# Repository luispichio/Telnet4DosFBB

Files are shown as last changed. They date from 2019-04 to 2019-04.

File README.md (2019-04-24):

# Telnet4DosFBB
Cliente / Servidor Telnet (Tunel TCP <-> Serial) para DosFBB

Conversor que simula modem teléfonico conectado a puerto serie permitiendo...

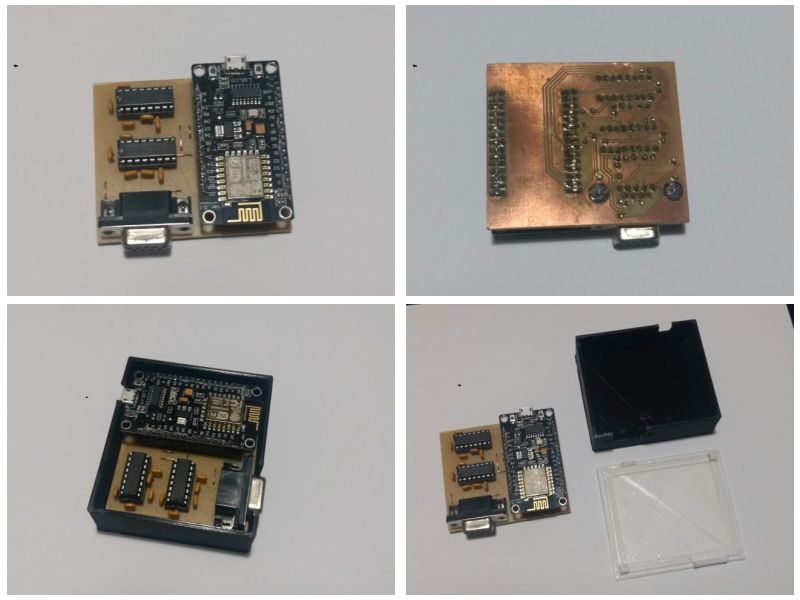
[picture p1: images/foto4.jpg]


# Limitaciones del sistema
1. Una conexión entrante / saliente a la vez: La interfaz de módem telefónico es para conexiones M2M (máquina a máquina).
2. Falso "Telnet": No se reconocen comandos específicos del protocolo, simplemente es un "tunel" TCP <-> Serial.
3. Ancho de banda acotado a interfaz de puerto serial / capacidad de procesamiento de la pc. Con FBBIOS > 1.3 se puede utilizar 56kbps en puerto serie (si la pc lo permite).
4. ...

# Conexionado
El conversor emula (y utiliza) todas las señales de control de un módem estándar.

El cable que debe utilizarse es un DTE <-> DCE con conexión pin a pin (sin inversiones) en los pines: 

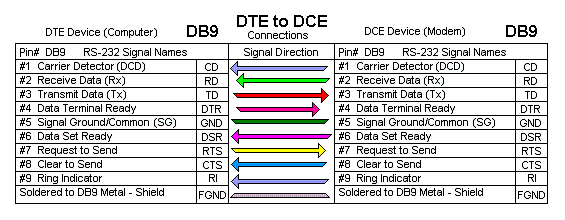
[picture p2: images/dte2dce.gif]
Cable DTE <-> DCE


Para mayor información consultar la documentación oficial: http://www.f6fbb.org/fbbdoc/fmtphnmo.htm

# Configuración

## BBS

Los usuarios del BBS no tiene autorización por defecto para conectar al BBS a traves del módem (Telnet / TCP en nuestro caso).

El SysOp debe habilitar la autorización para acceso por módem para cada usuario vía el comando de SysOP `EU` (editar usuario), habilitando el flag `M` (de módem) y luego asociando una contraseña con el comando `W`.

## Archivos

Se adjuntan archivos [ejemplo de configuración](config/)

### APPEL.BAT
Debe incluír la inicialización del driver fbbios previo a la carga de 'serv.exe'.

Sintaxis: `FBBIOS [# puerto] [dirección de puerto] [# irq]`.

Para mayor información consultar la documentación oficial: http://www.f6fbb.org/fbbdoc/fmtfbbio.htm

```
fbbios 1 03F8 4
serv %1
```

### PORT.SYS

Cantidad de puertos / TNC acorde al sistema
```
#Ports TNCs
1      1
```

Número de puerto serie, interfaz (3 -> Módem telefónico con FBBIOS), dirección de puerto y velocidad en baudios.
Se utiliza 57600 (máximo soportado por FBBIOS >1.3) para mejor rendimiento aunque puede no ser funcional dependiendo de las capacidades del hardware / pc.
La misma configuración aplica al driver FBBIOS que debe precargarse en APPEL.BAT.

```
#Com Interface Address (device)   Baud
1    3         3F8                57600
```

#### Configuración específica
* NbCh -> 1 (la interfaz soporta 1 canal)
* Com -> acorde a la configuración definida previamente
* M/P-Fwd -> inicio / intervalo de fwd de acuerdo al gusto (se aconseja no ser demasiado agresivo)
* Mode -> UMR (U = Normal, M = Módem telefónico, R = Permite conctar en solo lectura aunque no se tengan las credenciales de acceso).
* El resto de los parámetros son ignorados (creo) por la interfaz.

```
# Same number of lines as TNCs:
#
#TNC NbCh Com MultCh Pacln Maxfr NbFwd MxBloc M/P-Fwd Mode Freq
0    0    0   0      0     0     0     0      00/60   ---- File-fwd.
1    1    1   1      250   1     1     5      10/30   UMR  Telnet
```

### INITTNCx.SYS
Lista de comenados que envía el FBB al inicializar y posterior a una conexión.

Reemplazar `x` por número de TNC (depende de configuración en `PORT.SYS`).

Permite configurar parámetros de inicialización del conversor, tales como:
1. SSID y Contraseña de WiFi.
2. DDNS (duckdns.org).
3. Puerto de escucha de servidor telnet.
4. Estado activo / inactivo (fuera de servicio) del servidor telnet.
5. Reinicio del conversor.

Detalle de comandos soportados:

* `C$host:port` -> `host:port`: Servidor / puerto al que conectar.
* `SSID$ssid` -> `ssid`: SSID del WiFi a conectar
* `PASS$password` -> `password`: Contraseña de la red de WiFi
* `PORT$numero` -> `numero`: Puerto de Telnet (conexiones entrantes)
* `DUCK_DNS_UPDATE_TIME$tiempo` -> `tiempo` -> ...
* `DUCK_DNS_DOMAIN$dominio` -> `dominio`: ...
* `DUCK_DNS_TOKEN$token` -> `token`: ...
* `ONLINE$` -> Conversor "en linea": Atiende las conexiones entrantes)
* `OFFLINE$` -> Conversor "fuera de línea": Rechaza (y saluda) las conexiones entrantes.
* `RESET$` -> Reinicio del conversor
  
### MAINTx.SYS

Lista de comenados que envía el FBB al entrar en modo mantenimiento (DOS Gateway, al salir, etc).

Reemplazar `x` por número de TNC (depende de configuración en `PORT.SYS`).

Comando "utilizable":

* `OFFLINE$` -> Conversor "fuera de línea": Rechaza (y saluda) las conexiones entrantes.

### Archivo de forward

La sintaxis del comando de llamada difiere del utilizado en las versiones de FBB que soportal telnet:
Sintaxis: `^MC$$host:puerto^M`

`^M` previo -> para eliminar otro comando / basura que pueda estar encolado en la interfaz.

`C$$host:puerto` -> Conectar a `host` : `puerto` (si no se especifica este último se utiliza 23).

`^M` final -> para que el comando sea aceptado.

```
C C LW6DIO ^MC$$lw6dio.duckdns.org:6300^M
```

### Parámetros configurables desde el Firmware (código fuente)

```
// Modo depuración
// Utilizado para observar el comportamiento del conversor vía puerto serial.
#define DEBUG_MODE
#define DEBUG_BAUD_RATE                             57600

// Generales
// Velocidad en baudios del puerto serial.
#define SERIAL_BAUDRATE                             57600
// Puerto del servidor TCP (conexiones entrantes)
#define DEFAULT_TELNET_PORT                         6300
// Tiempo de reinicio si el conversor no puede conectarse a WiFi (se asume algún problema en hardware / software / externo y que un reinicio "lo pueda solucionar")
#define WIFI_DISCONNECTED_RESET_TIMEOUT_MINUTES     5.0f
// Tiempo de reinicio por inactividad (idem anterior).
#define WITHOUT_ACTIVITY_RESET_TIMEOUT_MINUTES      90.0f
// Tiempo de desconexión automática por inactividad de clientes (tener en cuenta que una vez iniciada la conexión el FBB no controla el estado del cliente TCP y este es el único método para garantizar la liberación)
#define DEFAULT_CLIENT_INACTIVITY_TIMEOUT_SECONDS   60

// Parámetros internos (no se recomienda la modificación)
#define SERIAL_RX_BUFFER_SIZE                       4096
#define SERIAL_RX_BUFFER_CTS_TARGET                 3072

#define TCP_2_SERIAL_BUFFER_SIZE                    8192
#define TCP_RX_FRAME_TIMEOUT                        50
#define SERIAL_2_TCP_BUFFER_SIZE                    1500  //1460?
#define SERIAL_RX_FRAME_TIMEOUT                     50
```

# Referencias
1. Documentación oficial: http://www.f6fbb.org/fbbdoc/doc.htm
2. Espejo en este repositorio: https://luispichio.github.io/Telnet4DosFBB/ (la documentación oficial suele estar fuera de línea)

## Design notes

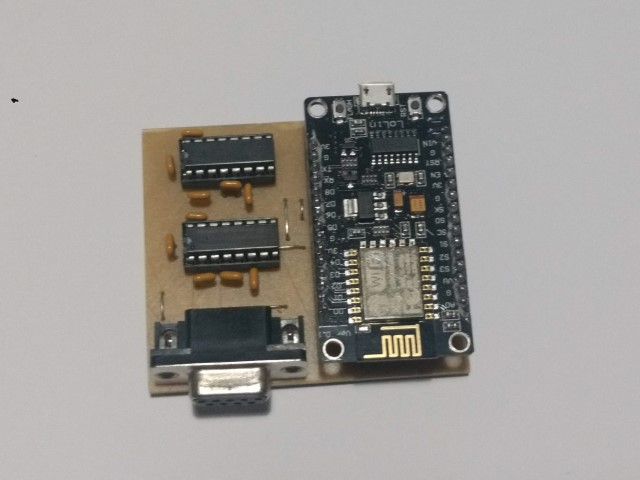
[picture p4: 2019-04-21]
images/foto0.jpg

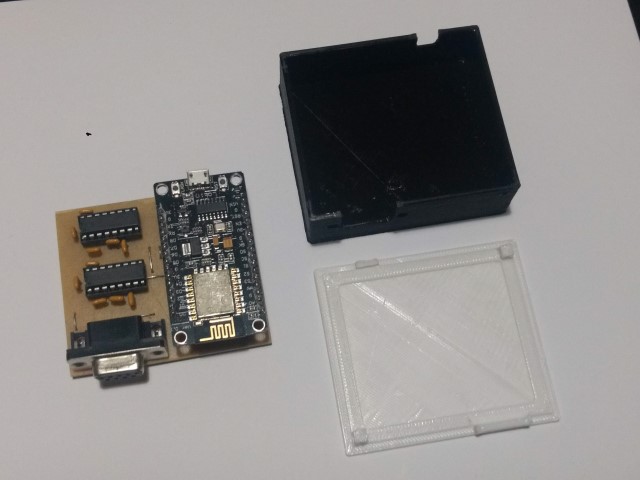
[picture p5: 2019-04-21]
images/foto3.jpg

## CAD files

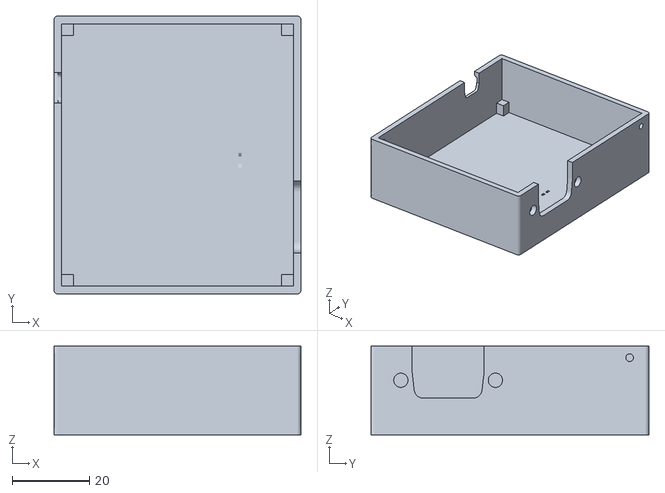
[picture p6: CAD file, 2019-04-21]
box/Caja - Telnet4DosFBB(19112017_0053).stl
64.0 x 72.0 x 23.0

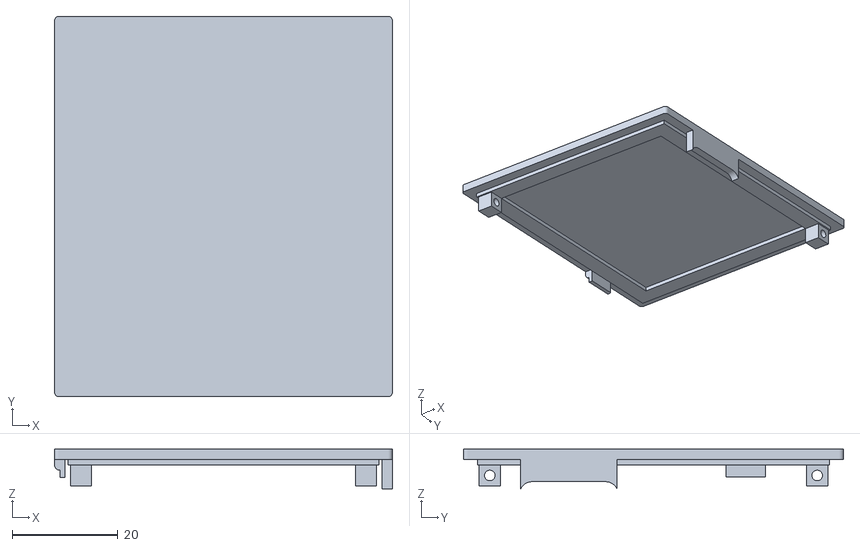
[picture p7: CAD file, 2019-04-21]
box/Tapa - Telnet4DosFBB(19112017_0054).stl
64.0 x 72.0 x 7.55

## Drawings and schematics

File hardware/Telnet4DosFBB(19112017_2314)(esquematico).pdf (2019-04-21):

U2

U3

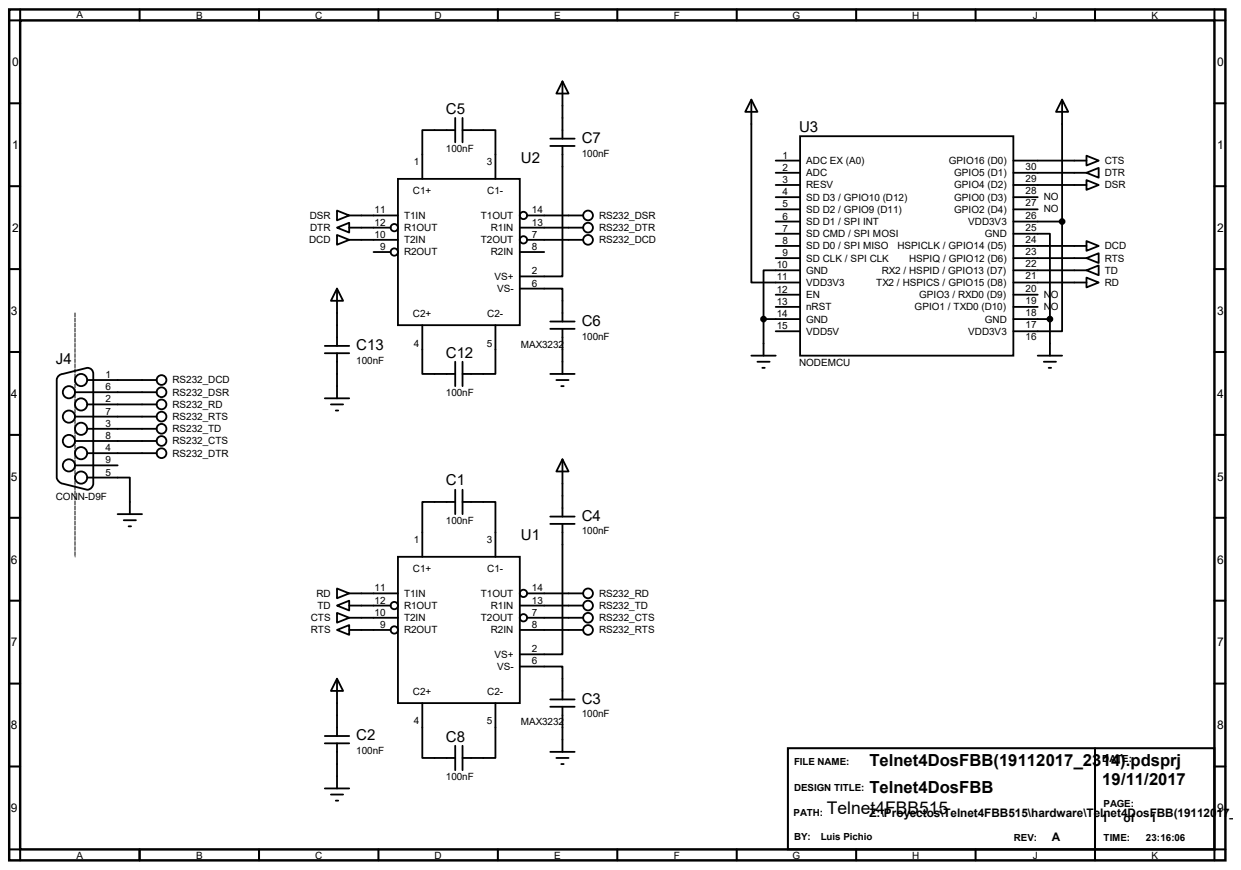
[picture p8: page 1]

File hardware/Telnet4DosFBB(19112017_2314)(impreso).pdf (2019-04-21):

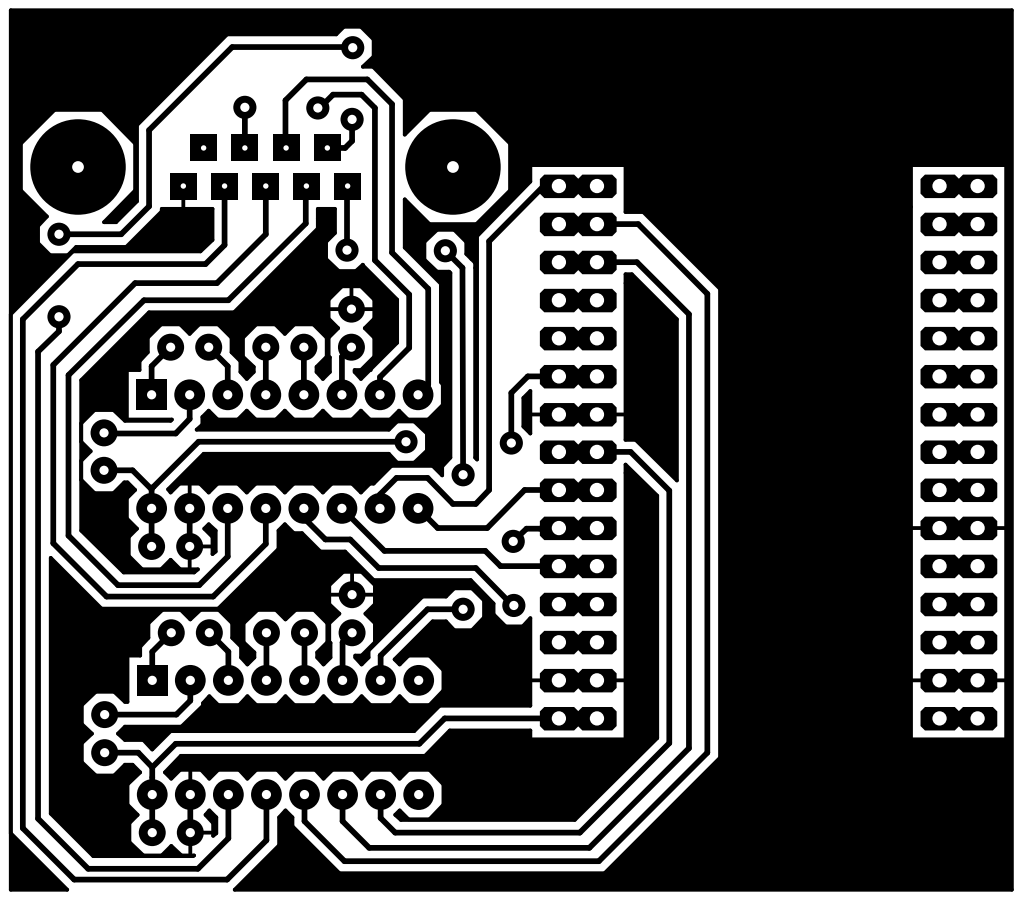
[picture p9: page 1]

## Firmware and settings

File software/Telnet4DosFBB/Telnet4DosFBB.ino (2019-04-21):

/*
MIT License

Copyright (c) 2017 Luis Pichio | https://sites.google.com/site/luispichio/ | https://github.com/luispichio

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
THE SOFTWARE IS PROVIDED "AS IS", WITHOUT WARRANTY OF ANY KIND, EXPRESS OR
IMPLIED, INCLUDING BUT NOT LIMITED TO THE WARRANTIES OF MERCHANTABILITY,
FITNESS FOR A PARTICULAR PURPOSE AND NONINFRINGEMENT. IN NO EVENT SHALL THE
AUTHORS OR COPYRIGHT HOLDERS BE LIABLE FOR ANY CLAIM, DAMAGES OR OTHER
LIABILITY, WHETHER IN AN ACTION OF CONTRACT, TORT OR OTHERWISE, ARISING FROM,
OUT OF OR IN CONNECTION WITH THE SOFTWARE OR THE USE OR OTHER DEALINGS IN THE
SOFTWARE.
*/

#include <ESP8266WiFi.h>
#include <ESP8266HTTPClient.h>
#include "cbuf.h"
#include <EEPROM.h>
#include "CRC8.h"
#include "Utils.h"

//-----------------------------------------------------------------------------
//#define DEBUG_MODE
#define DEBUG_BAUD_RATE                             57600
//-----------------------------------------------------------------------------
#define SERIAL_BAUDRATE                             57600
#define DEFAULT_TELNET_PORT                         6300
#define WIFI_DISCONNECTED_RESET_TIMEOUT_MINUTES     5.0f  //m
#define WITHOUT_ACTIVITY_RESET_TIMEOUT_MINUTES      90.0f  //m
#define DEFAULT_CLIENT_INACTIVITY_TIMEOUT_SECONDS   60  //s
//-----------------------------------------------------------------------------
// ↓↓↓↓↓ parámetros internos ↓↓↓↓↓
//-----------------------------------------------------------------------------
#define SERIAL_RX_BUFFER_SIZE                       4096
#define SERIAL_RX_BUFFER_CTS_TARGET                 3072
//-----------------------------------------------------------------------------
#define TCP_2_SERIAL_BUFFER_SIZE                    8192
#define TCP_RX_FRAME_TIMEOUT                        50
#define SERIAL_2_TCP_BUFFER_SIZE                    1500  //1460?
#define SERIAL_RX_FRAME_TIMEOUT                     50
//-----------------------------------------------------------------------------
//pines
#define CTS_PIN                                     16
#define DCD_PIN                                     14
#define DSR_PIN                                     4
#define RTS_PIN                                     12
#define DTR_PIN                                     5
//-----------------------------------------------------------------------------
//estructura de configuración
//se almacena una única copia en memoria no volátil (flash en este caso)
typedef struct s_config{ 
  char wifiSSID[32];  //ssid de wifi al que se conecta el dispositivo
  char wifiPassword[32];  //contraseña del wifi
  uint16_t serverPort;  //puerto de servidor telnet
  uint16_t clientInactivityTimeout;  //tiempo de desconexión por unactividad (cliente)
  uint16_t duckDNSUpdateTime;  //tiempo de actualización de DNS (duckdns.org)
  char duckDNSDomain[64];  //dominio
  char duckDNSToken[64];  //token
  uint8_t crc; //control de integridad de la estructura
} t_config;
//-----------------------------------------------------------------------------
//variables globales
t_config g_config;  //configuración del sistema (se almacena también una copia en memoria no volátil)
WiFiServer *server;  //server telnet (falso telnet)
WiFiClient client;  //cliente entrante (conexión atentida del servidor) o saliente
long lastClientActivity;  //ultima actividad de cliente (utilizado para reinicio periódico)
bool online = true;  //sistema en línea
long lastWiFiStatusConnected;  //último estado "conectado" de WiFi
long lastDNSUpdate;

#ifdef DEBUG_MODE
  #include <SoftwareSerial.h>
  SoftwareSerial* logger;
  long gTCP2SerialByteCount = 0;
  long gSerial2TCPByteCount = 0;
#endif
//-----------------------------------------------------------------------------
long secondsToMilliseconds(float seconds){
  return seconds * 1000UL;
}
//-----------------------------------------------------------------------------
long minutesToMilliseconds(float minutes){
  return minutes * 60000UL;
}
//-----------------------------------------------------------------------------
long hoursToMilliseconds(float hours){
  return hours * 3600000UL;
}
//-----------------------------------------------------------------------------
//inicialización
void setup() {
  pinMode(DCD_PIN, OUTPUT);
  digitalWrite(DCD_PIN, HIGH);
  pinMode(CTS_PIN, OUTPUT);
  digitalWrite(CTS_PIN, HIGH);
  pinMode(DSR_PIN, OUTPUT);
//  digitalWrite(DSR_PIN, LOW);
  digitalWrite(DSR_PIN, HIGH);
  pinMode(RTS_PIN, INPUT);
  pinMode(DTR_PIN, INPUT);

//puerto serial  
  Serial.begin(SERIAL_BAUDRATE, SERIAL_8N1);
  Serial.setRxBufferSize(SERIAL_RX_BUFFER_SIZE);
  Serial.flush();
  Serial.swap();  //swap a gpio alternativo
  
#ifdef DEBUG_MODE
  logger = new SoftwareSerial(3, 1);
  logger->begin(DEBUG_BAUD_RATE);
  logger->println("\n\nDEBUG_MODE");
#endif

//configuración (almacenada en memoria no volátil)
  EEPROM.begin(512);
  EEPROM.get(0, g_config);
  if (CRC8.calc(0xFF, (uint8_t *)&g_config, offsetof(t_config, crc)) != g_config.crc){  //si la copia tiene integridad incorrecta -> configuración por defecto
#ifdef DEBUG_MODE  
      logger->println("Factory defaults!");
#endif    
      strcpy(g_config.wifiSSID, "");
      strcpy(g_config.wifiPassword, "");
      g_config.serverPort = DEFAULT_TELNET_PORT;
      g_config.clientInactivityTimeout = DEFAULT_CLIENT_INACTIVITY_TIMEOUT_SECONDS;
      g_config.duckDNSUpdateTime = 0;  //DNS desactivado por defecto
      strcpy(g_config.duckDNSDomain, "");
      strcpy(g_config.duckDNSToken, "");
      g_config.crc = CRC8.calc(0xFF, (uint8_t *)&g_config, offsetof(t_config, crc));
      EEPROM.put(0, g_config);
      EEPROM.commit();
  }
   
//wifi
  if (strlen(g_config.wifiSSID))
    WiFi.begin(g_config.wifiSSID, g_config.wifiPassword);  //intentamos conectar
  else
    WiFi.begin();
#ifdef DEBUG_MODE  
  logger->print("Conectando a "); logger->println(g_config.wifiSSID);
#endif  
  while ((WiFi.status() != WL_CONNECTED) && (millis() < secondsToMilliseconds(10.0f)))  //por 10s
    delay(1000);
#ifdef DEBUG_MODE    
  if (WiFi.status() == WL_CONNECTED){
    logger->print("Listo! Para conectar utilice 'telnet ");
    logger->print(WiFi.localIP());
    logger->print(":");
    logger->print(g_config.serverPort);
    logger->println("'");
  } else {
    logger->print("No se pudo conectar a ");
    logger->println(g_config.wifiSSID);
  }
#endif

//servidor telnet (falso telnet en rigor)
  server = new WiFiServer(g_config.serverPort);
  server->begin();
  server->setNoDelay(false);

  lastClientActivity = lastWiFiStatusConnected = lastDNSUpdate = millis();
}
//-----------------------------------------------------------------------------
bool clientConnected(){
  return client && client.connected();
}
//-----------------------------------------------------------------------------
//procesa trama de comandos
void processFBBLine(char *frame){
  char *cmd;
  char *host;
  char *_port;
  int port;
  bool _connected;
  byte retrys = 3;
#ifdef DEBUG_MODE  
  logger->println(frame);
#endif

//comando conectar
  if (cmd = strstr(frame, "C$")){
    cmd += 2;
    host = strtok(cmd, ":");
    _port = strtok(NULL, ":");
    port = atoi(_port);
    if (port == 0)
      port = 23;
    if (host){
      while (!(_connected = client.connect(host, port)) && retrys){
        retrys--;
        delay(100);
      }
      if (_connected){
//        Serial.print("Conectando a "); Serial.print(host); Serial.print(":"); Serial.println(port);
        client.setNoDelay(false);
        digitalWrite(DCD_PIN, LOW);
        lastClientActivity = millis();
      } else {
//        Serial.print("Imposible conectar a "); Serial.print(host); Serial.print(":"); Serial.println(port);
        digitalWrite(DCD_PIN, LOW);
        delay(100);
        digitalWrite(DCD_PIN, HIGH);
      }
    }
  }

//comando SSID de wifi
  if (cmd = strstr(frame, "SSID$")){
    cmd += strlen("SSID$");
    if (strlen(cmd) < 31)
      strcpy(g_config.wifiSSID, cmd);
  }

//comando password de wifi
  if (cmd = strstr(frame, "PASS$")){
    cmd += strlen("PASS$");
    if (strlen(cmd) < 31)
      strcpy(g_config.wifiPassword, cmd);
  }
  
//puerto de servidor telnet
  if (cmd = strstr(frame, "PORT$")){
    cmd += strlen("PORT$");
    g_config.serverPort = atoi(cmd);
  }

//DDNS
  if (cmd = strstr(frame, "DUCK_DNS_UPDATE_TIME$")){
    cmd += strlen("DUCK_DNS_UPDATE_TIME$");
    g_config.duckDNSUpdateTime = atoi(cmd);
  }
  if (cmd = strstr(frame, "DUCK_DNS_DOMAIN$")){
    cmd += strlen("DUCK_DNS_DOMAIN$");
    if (strlen(cmd) < 63)
      strcpy(g_config.duckDNSDomain, cmd);
  }
  if (cmd = strstr(frame, "DUCK_DNS_TOKEN$")){
    cmd += strlen("DUCK_DNS_TOKEN$");
    if (strlen(cmd) < 63)
      strcpy(g_config.duckDNSToken, cmd);
  }
  
//almacenamos configuración en caso de que haya cambios
  uint8_t crc = CRC8.calc(0xFF, (uint8_t *)&g_config, offsetof(t_config, crc));
  if (crc != g_config.crc){
    g_config.crc = crc;
    EEPROM.put(0, g_config);
    EEPROM.commit();
  }

//bbs en línea
  if (strstr(frame, "ONLINE$"))
    online = true;

//bbs fuera de línea
  if (strstr(frame, "OFFLINE$"))
    online = false;

//reinicio (para aplicar la configuración)  
  if (strstr(frame, "RESET$")){
    Serial.swap();
    ESP.restart();
  }
}
//-----------------------------------------------------------------------------
//procesa trama de puerto serial
void processSerialFrame(uint8_t *frame, int size){
  static char bufferRX[256];
  static int bufferSize = 0;  
  while (size--){
    uint8_t b = *frame; frame++;
    if ((b == 0x0a) || (b == 0x0d)){
      if (bufferSize){
        bufferRX[bufferSize] = 0;
        processFBBLine(bufferRX);
        bufferSize = 0;
      }
    } else
      if (bufferSize < 255)  //si mayor a tamaño de buffer -> se pierde contenido
        bufferRX[bufferSize++] = b;
  }
}
//-----------------------------------------------------------------------------
//manejador de conexiones entrantes (servidor telnet)
//atiende nuevos clientes
//envía mensaje y rechaza en caso de no poder atender la conexión
bool check4Clients(void){
  if (server->hasClient()){  //hay nuevo cliente?
    if (online){  //está el servicio en línea?
      if (clientConnected()){  //tenemos cliente -> no podemos atender al nuevo
        WiFiClient _client = server->available();
        _client.println("Todos los canales están ocupados.");  //mensaje de "canales ocupados"
        _client.println("Intente en otro momento.");
        delay(0);
        _client.stop();
      } else {  //no tenemos cliente, tomamos la conexión
        if (client)  //tenemos cliente (pero no está conectado)
          client.stop();
        client = server->available();
        client.setNoDelay(false);
        lastClientActivity = millis();
        client.print("\xff\xfc\x01\xff\xfe\x01");  //IAC WONT ECHO & IAC DONT ECHO
        delay(0);
        digitalWrite(DCD_PIN, LOW);  //señal de DCD para que el BBS "atienda la conexión"
//        client.flush();
      }
    } else {  //el servicio no está en línea
        WiFiClient _client = server->available();
        _client.println("BBS fuera de línea");  //mensaje de "fuera de línea"
        _client.println("Intente en otro momento.");
        delay(0);
        _client.stop();      
    }
  }  
  return clientConnected();

}
//-----------------------------------------------------------------------------
//recepción de tramas por tcp y reenvío a puerto serie
void tcp2Serial(){
  static uint8_t buffer[TCP_2_SERIAL_BUFFER_SIZE];  //estático para evitar uso de stack (fragmentación? no debería)
  uint16_t bufferLast = 0;
  uint16_t bufferFirst = 0;
  uint16_t lastAvailable;
  long lastRX;
  uint16_t available;  

  if (available = client.available()){
    lastRX = millis();
    lastAvailable = available;
    do {
      if (bufferFirst < bufferLast){  //hay contenido para el puerto serie
        if (available = Utils::Min(bufferLast - bufferFirst, Serial.availableForWrite())){  //hay contenido / espacio en FIFO de puerto serie?
          Serial.write(buffer + bufferFirst, available);  //enviamos por puerto serial (al FIFO)
          bufferFirst += available;
        }
      }
      if (bufferFirst >= bufferLast){  //puerto serie sin trabajo? (quiere decir que podemos atender lo que llega por TCP)
        bufferLast = Utils::Min(client.available(), TCP_2_SERIAL_BUFFER_SIZE);
        client.read(buffer, bufferLast);
        bufferFirst = 0;
#ifdef DEBUG_MODE        
        gTCP2SerialByteCount += bufferLast;
#endif        
      }
      if ((available = client.available()) != lastAvailable){  //hay RX?
          lastAvailable = available;
          lastRX = millis();          
      }    
      delay(0);
      digitalWrite(CTS_PIN, Serial.available() > SERIAL_RX_BUFFER_CTS_TARGET);  //si se alcanza cierto contenido en buffer de rx de puerto serie -> cerramos la ventana de RX del FBB  
    } while (available || (bufferFirst < bufferLast) || (millis() - lastRX < TCP_RX_FRAME_TIMEOUT));
    lastClientActivity = millis();
  }      
}
//-----------------------------------------------------------------------------
//recepción de tramas por puerto serie y reenvío a cliente TCP
void serial2TCP(bool _clientConnected){
  static uint8_t buffer[SERIAL_2_TCP_BUFFER_SIZE];  //estático para evitar uso de stack (fragmentación? no debería)
  uint16_t lastAvailable;
  long lastRX;
  uint16_t available;      

  if (available = Serial.available()){
    lastRX = millis();
    lastAvailable = available;
    do {
      if (_clientConnected){  //si hay cliente conectado -> enviamos datos al cliente
        if (available = Utils::Min(available, SERIAL_2_TCP_BUFFER_SIZE, client.availableForWrite())){  //si hay datos disponibles en buffer de RX de Serial => limitamos a tamaño de buffer  
          Serial.readBytes(buffer, available);  //leemos los bytes
          client.write((const uint8_t *)buffer, available);  //enviamos trama al cliente
          lastClientActivity = millis();
  #ifdef DEBUG_MODE         
          gSerial2TCPByteCount += available;
  #endif
        }
      } else {  //sinó, enviamos a procesador de comandos
        available = Utils::Min(Serial.available(), SERIAL_2_TCP_BUFFER_SIZE);  //limitamos a tamaño de buffer
        Serial.readBytes(buffer, available);  //leemos los bytes
        processSerialFrame(buffer, available);  //procesamos como trama de comandos
      }
      
      if ((available = Serial.available()) != lastAvailable){  //hay RX?
          lastAvailable = available;
          lastRX = millis();          
      }    
      delay(0);
      digitalWrite(CTS_PIN, Serial.available() > SERIAL_RX_BUFFER_CTS_TARGET);  //si se alcanza cierto contenido en buffer de rx de puerto serie -> cerramos la ventana de RX del FBB  
    } while (available || (millis() - lastRX < SERIAL_RX_FRAME_TIMEOUT));
  }
}
//-----------------------------------------------------------------------------
//actualización de DNS (duckdns.org)
bool doDNSUpdate(){
  char str[256];
  HTTPClient http;
  sprintf(str, "http://www.duckdns.org/update?domains=%s&token=%s", g_config.duckDNSDomain, g_config.duckDNSToken);
#ifdef DEBUG_MODE   
  logger->println(str);
#endif
  http.begin(str);
//  http.addHeader("Content-Type", "application/x-www-form-urlencoded");
  if (http.GET() == 200){
    http.getString().toCharArray(str, 256);
#ifdef DEBUG_MODE    
    logger->println(str);
#endif
    if (strstr(str, "OK"))
      return true;
  }
  return false;
}
//-----------------------------------------------------------------------------
//loop de la aplicación
long oneSecond = millis();
void loop() {
  bool _clientConnected = check4Clients();
  digitalWrite(DCD_PIN, !_clientConnected);  //cliente conectado -> señal de atender al FBB
  digitalWrite(CTS_PIN, Serial.available() > SERIAL_RX_BUFFER_CTS_TARGET);  //si se alcanza cierto contenido en buffer de rx de puerto serie -> cerramos la ventana de RX del FBB  
  
  if (client) tcp2Serial();
  serial2TCP(_clientConnected);
    
  //chequeos periódicos
  if (millis() - oneSecond > 1000){
#ifdef DEBUG_MODE 
    char str[128];
    long delta = millis() - oneSecond;
    sprintf(str, "%li %li %li %li %li", 1000 * gTCP2SerialByteCount / delta, 1000 * gSerial2TCPByteCount / delta, millis() - lastClientActivity, ESP.getFreeHeap(), ESP.getHeapFragmentation());
    gSerial2TCPByteCount = gTCP2SerialByteCount = 0;
    logger->println(str);
#endif
    oneSecond = millis();
    //desconexión por inactividad / fuera de línea
    if (_clientConnected && (millis() - lastClientActivity > secondsToMilliseconds(g_config.clientInactivityTimeout) || !online))
      client.stop();
    //actualización de DNS
    if ((!_clientConnected) && g_config.duckDNSUpdateTime && (millis() - lastDNSUpdate > secondsToMilliseconds(g_config.duckDNSUpdateTime))){
      doDNSUpdate();
      lastDNSUpdate = millis();
    }
    //reinicio por inactividad / falta de WiFi (por cuestiones de estabilidad de la plataforma)
    if (millis() - lastClientActivity > minutesToMilliseconds(WITHOUT_ACTIVITY_RESET_TIMEOUT_MINUTES))
      ESP.restart();  
    //chequeo de WiFi
//    Serial.print(WiFi.status());
    if (WiFi.status() == WL_CONNECTED)
      lastWiFiStatusConnected = millis();
    if (millis() - lastWiFiStatusConnected > minutesToMilliseconds(WIFI_DISCONNECTED_RESET_TIMEOUT_MINUTES))
      ESP.restart();
  }
}
//-----------------------------------------------------------------------------

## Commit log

2019-04-21 Versión "de producción"
    Actualizaciones varias:
    Esquemático, Impreso
    Software
    Fotos
    Modelo 3D del gabiente
    Ejemplos de configuración
    [Caja - Telnet4DosFBB(19112017_0053).stl, Tapa - Telnet4DosFBB(19112017_0054).stl]
2019-04-23 Descripción + Documentación de FBB (mirror)
    Descripción
    Instrucciones de uso
    Documentación de F6FBB (http://www.f6fbb.org/fbbdoc/doc.htm)
2019-04-23 fbbdoc -> docs
    Carpeta renombrada para habilitar GitHub Pages.
